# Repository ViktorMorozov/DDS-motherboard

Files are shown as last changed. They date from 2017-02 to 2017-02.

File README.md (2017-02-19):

# DDS-motherboard

A small motherboard to host a DDS AD9850, an Arduino Pro Clone and and an LCD. The project is composed of:
- Code to control the oscillation frequency through an AB encoder and display it in the LCD.
- KICad project with schematics and PCB design
- Milling file (G code) for CNC1610 and 0.1mm mill

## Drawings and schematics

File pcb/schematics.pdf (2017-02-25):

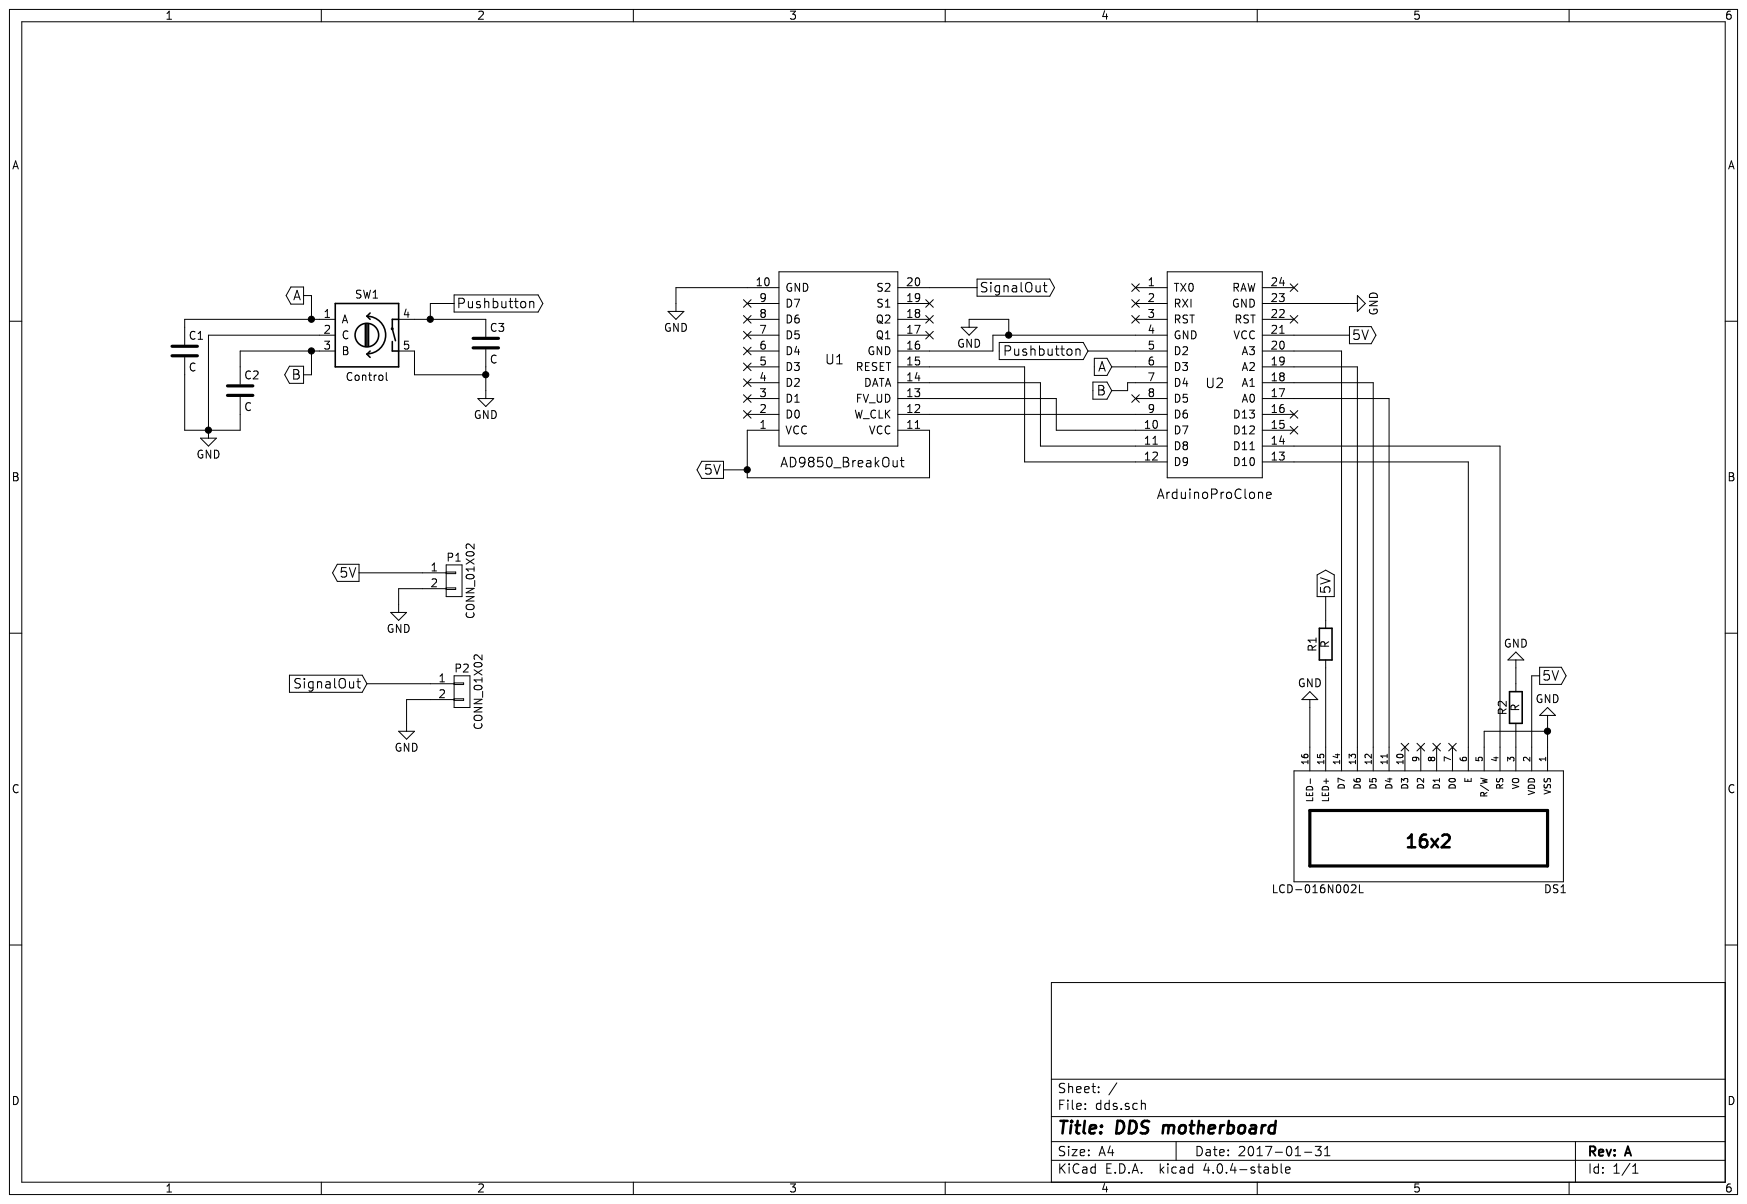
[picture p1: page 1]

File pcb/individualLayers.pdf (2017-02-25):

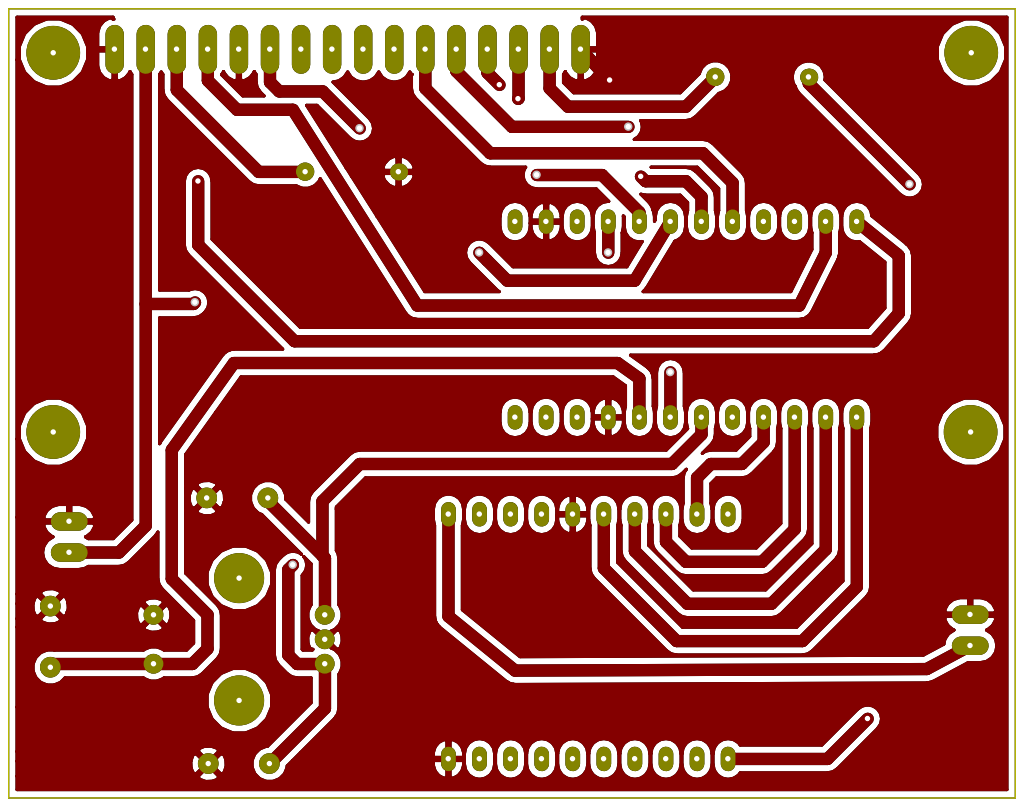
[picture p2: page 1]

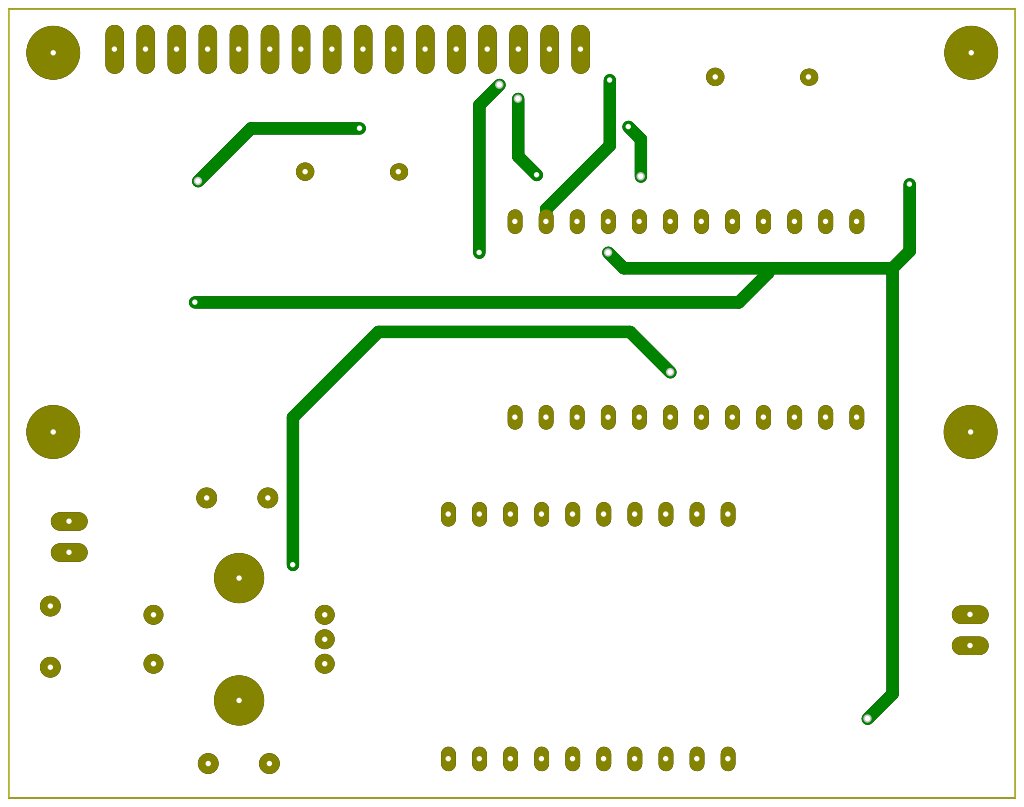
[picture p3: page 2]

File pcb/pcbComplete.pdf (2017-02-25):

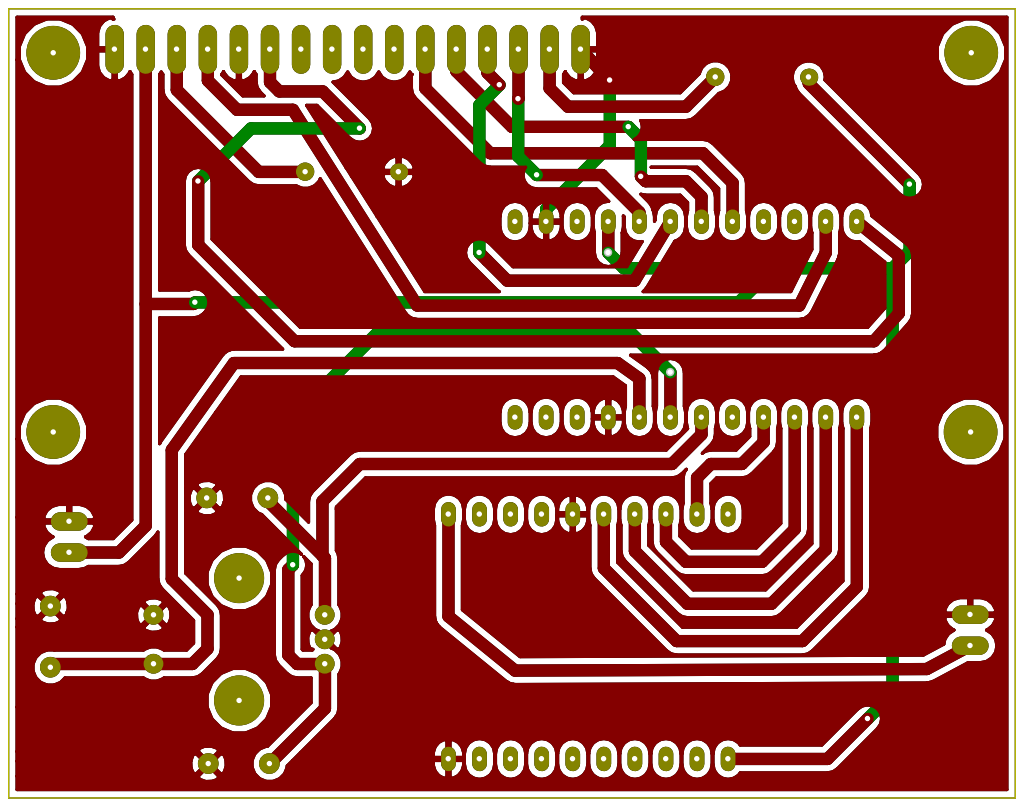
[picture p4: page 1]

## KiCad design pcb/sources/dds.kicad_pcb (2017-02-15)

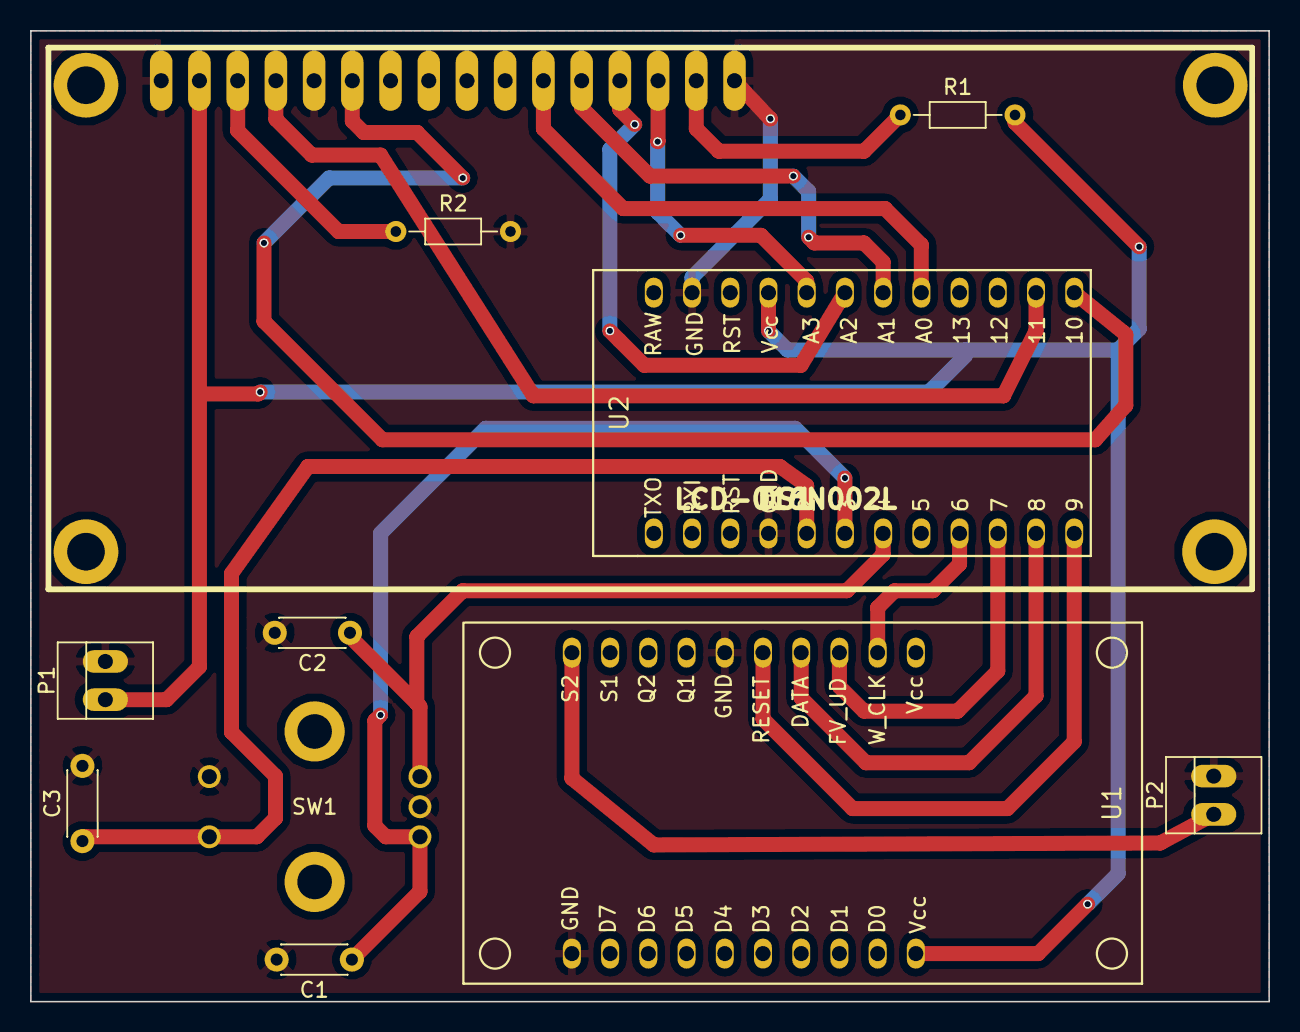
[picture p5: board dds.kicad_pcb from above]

Board: 2 copper layers, 82.3 x 64.5 mm, 11 parts (0 on the bottom side), 18 nets.

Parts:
C1, C2, C3: C; C_Disc_D4.3mm_W1.9mm_P5.00mm
DS1: LCD-016N002L; LCD-16x2
P1, P2: CONN_01X02; PINHEAD1-2
R1, R2: R; R_Axial_DIN0204_L3.6mm_D1.6mm_P7.62mm_Horizontal
SW1: Control; Encoder_PEC11-4215F-S00
U1: AD9850_BreakOut; AD9850_BreakoutBoard
U2: ArduinoProClone; ArduinoPro_Mini

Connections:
5V: DS1.2, P1.1, R1.2, U1.1, U1.11, U2.21
A: C1.1, SW1.1, U2.6
B: C2.1, SW1.3, U2.7
GND: C1.2, C2.2, C3.2, DS1.1, DS1.5, DS1.16, P1.2, P2.2, R2.2, SW1.2, SW1.5, U1.10, U1.16, U2.4, U2.23
unnamed: DS1.3, R2.1
unnamed: DS1.4, U2.14
unnamed: DS1.6, U2.13
unnamed: DS1.11, U2.17
unnamed: DS1.12, U2.18
unnamed: DS1.13, U2.19
unnamed: DS1.14, U2.20
unnamed: DS1.15, R1.1
unnamed: U1.12, U2.9
unnamed: U1.13, U2.10
unnamed: U1.14, U2.11
unnamed: U1.15, U2.12
Pushbutton: C3.1, SW1.4, U2.5
SignalOut: P2.1, U1.20

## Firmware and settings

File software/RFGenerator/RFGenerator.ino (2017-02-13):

#include <LiquidCrystal.h>
#include <AD9850.h>    //http://github.com/F4GOJ/AD9850

#define MHZ_10  10000000
#define MHZ     1000000
#define KHZ_100 100000
#define KHZ_10  10000
#define KHZ     1000
#define HZ_100  100
#define HZ_10   10

#define MAX_F     40000000
#define MIN_F     500000
#define INITIAL_F 7000000

#define IRQ_FILTER_MS 5
#define CW  1  // Clockwise rotation
#define CCW -1 // Counter Clockwise rotation

#define COMPENSATION 100

// Steps used in the 
double step[5] = {HZ_100,KHZ,KHZ_10,KHZ_100,MHZ};
int currentStep = 0; // Point to the current step
double freq = INITIAL_F; // Frequency in Hz

// Updated by the ISR (Interrupt Service Routine)
int updateScreenFlag = 1;

// Pin connections
const int PinA = 3;   // PinA and PinB for AB encoder
const int PinB = 4;
const int PinSW = 2;  // Push button

// Setup the LCD connections
LiquidCrystal lcd(11, 10, A0, A1, A2, A3);

void displayStep();
void displayFreq();
long getDigit(long mask, long freq);

void setup() {

  // Rotary pulses are INPUTs
  pinMode(PinA, INPUT);
  pinMode(PinB, INPUT);

  // Switch is floating so use the in-built PULLUP so we don't need a resistor
  pinMode(PinSW, INPUT_PULLUP);

  digitalWrite(PinA, HIGH);
  digitalWrite(PinB, HIGH); // Enable the internal pull ups in both input pins

  // Attach the routine to service the interrupts
  attachInterrupt(digitalPinToInterrupt(PinA), isrAB, LOW);
  
  lcd.begin(16, 2);
  DDS.begin(6, 7, 8, 9);
  DDS.calibrate(124999000);
  DDS.setfreq(freq, 0);
}

void loop() {
  
  // Is someone pressing the rotary switch?
  if ((!digitalRead(PinSW))) {
    //virtualPosition = 0;
    while (!digitalRead(PinSW))
      delay(10);
     currentStep = ((currentStep + 1) % 5);
    updateScreenFlag = 1;
  }
  
    DDS.setfreq(freq-COMPENSATION, 0);
    displayFreq();

    if (updateScreenFlag)
    {
      displayStep();
      updateScreenFlag = 0;
    }
}

void displayStep()
{
    lcd.clear();
    lcd.setCursor(0,1);
    lcd.print("Step:");
    lcd.setCursor(8,1);

    switch(currentStep) {
      case 0:
        lcd.print("100  Hz");
        break;
      case 1:
        lcd.print("  1 KHz");
        break;
      case 2:
        lcd.print(" 10 KHz");
        break;
      case 3:
        lcd.print("100 KHz");
        break;
      case 4:
        lcd.print("  1 MHz");
        break;
    }
}

void displayFreq()
{
    lcd.setCursor(0,0);
    lcd.print("Freq:");
    lcd.setCursor(6,0);
    lcd.setCursor(7,0);

    if ( freq >= MHZ_10) 
    {
      lcd.print((int) getDigit(MHZ_10,(long)freq));
    }
    else
    {
      lcd.print(" ");
    }
    
    lcd.setCursor(8,0);
    lcd.print((int)getDigit(MHZ,(long)freq % MHZ_10));
    lcd.setCursor(9,0);
    lcd.print(".");
    lcd.setCursor(10,0);
    lcd.print((int)getDigit(KHZ_100,(long)freq % MHZ));
    lcd.setCursor(11,0);
    lcd.print((int)getDigit(KHZ_10,(long)freq % KHZ_100));
    lcd.setCursor(12,0);
    lcd.print((int)getDigit(KHZ,(long)freq % KHZ_10));
    lcd.setCursor(13,0);
    lcd.print(",");
    lcd.setCursor(14,0);
    lcd.print((int)getDigit(HZ_100,(long)freq % KHZ));
    lcd.setCursor(15,0);
    lcd.print((int)getDigit(HZ_10,(long)freq % HZ_100));
}

long getDigit(long mask, long freq)
{
    return (freq/mask);
}


// https://github.com/futureshocked/arduino_sbs/blob/master/RotaryEncoder/rotaryEncoder/rotaryEncoder.ino
void isrAB ()  {
  
  static unsigned long lastInterruptTime = 0;
  unsigned long interruptTime = millis();
  char direction = 0;
  
  // If interrupts come faster than 5ms, assume it's a bounce and ignore
  if (interruptTime - lastInterruptTime > IRQ_FILTER_MS) {
    if (digitalRead(PinB) == LOW)
    {
      direction = CCW ;
    }
    else {
      direction = CW ;
    }

    if (freq >=MAX_F & direction == CW)
      freq = MAX_F;
    if (freq <= MIN_F & direction == CCW)
      freq = MIN_F;

    if ((freq >= MAX_F & direction == CCW) | 
      (freq <= MIN_F & direction == CW) |
      (freq > MIN_F & freq < MAX_F)
      )
      freq = freq + (direction * step[currentStep]);
      lastInterruptTime = interruptTime;
  }
}

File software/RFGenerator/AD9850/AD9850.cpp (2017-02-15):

/******************************************************************************************************************
 * Arduino library for AD9850
 * Created 23/08/2014
 * Christophe Caiveau f4goj@free.fr
 *
 * Use this library freely
 *
 * Hardware connections :
 * W_CLK   -> any pin
 * FQ_UD   -> any pin
 * DATA/D7 -> any pin
 * RESET   -> any pin
 *
 * Functions :
 * dds.begin(W_CLK pin, FQ_UD pin, DATA pin, RESET pin); Initialize the output pins and master reset the AD9850
 * dds.calibrate(frequency); Compensation of crystal oscillator frequency
 * dds.setfreq(frequency,phase); frequency in Hz, phase coded on 5 bits
 * dds.down(); power down mode reducing the dissipated power from 380mW to 30mW @5V
 * dds.up(); wake-up the AD9850
 *
 * AD9850 datasheet at http://www.analog.com/static/imported-files/data_sheets/AD9850.pdf
 *
 *****************************************************************************************************************/

#include "AD9850.h"

AD9850 DDS;

AD9850::AD9850() {

}

void AD9850::begin(int w_clk, int fq_ud, int data, int reset) {
	W_CLK = w_clk;
	FQ_UD = fq_ud;
	DATA = data;
	RESET = reset;
	deltaphase = 0;
	phase = 0;
	calibFreq = 125000000;
	begin_priv();
}

void AD9850::begin_priv() {
	pinMode(W_CLK, OUTPUT);
	pinMode(FQ_UD, OUTPUT);
	pinMode(DATA, OUTPUT);
	pinMode(RESET, OUTPUT);

	pulse(RESET);
	pulse(W_CLK);
	pulse(FQ_UD);
}

void AD9850::update() {

    for (int i=0; i<4; i++, deltaphase>>=8) {
     shiftOut(DATA, W_CLK, LSBFIRST, deltaphase & 0xFF);
    }
    shiftOut(DATA, W_CLK, LSBFIRST, phase & 0xFF);
    pulse(FQ_UD);
}


void AD9850::setfreq(double f, uint8_t p) {
	deltaphase = f * 4294967296.0 / calibFreq;
	phase = p << 3;
	update();
}


void AD9850::down() {
	pulse(FQ_UD);
	shiftOut(DATA, W_CLK, LSBFIRST, 0x04);
	pulse(FQ_UD);
}


void AD9850::up() {
	update();
}


void AD9850::calibrate(double TrimFreq)
{
	calibFreq = TrimFreq;
}


void AD9850::pulse(int pin) {
	digitalWrite(pin, HIGH);
	digitalWrite(pin, LOW);
}

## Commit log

2017-02-13 Added schematics and pcb design files
    [dds.kicad_pcb, dds.sch]
2017-02-13 Added initial version of the arduino firmware
2017-02-14 Gerber files for front layer and drill map.
    [dds-F.Cu.gbr, dds-drl_map.gbr, dds.drl]
2017-02-14 Gerber files moved and milling file created
    [dds-F.Cu.gbr, dds-drl_map.gbr, dds.drl]
2017-02-14 PDFs with schematics generated and files moved under sources folder
    [dds.kicad_pcb, dds.sch]
2017-02-14 Files moved to production and sources folder
    [dds.drl]
2017-02-15 Minor tracks re-route in front layer
    [dds.kicad_pcb]
2017-02-25 First milling attempt
    First milling attempt
2017-02-25 New production code with 0.1 mm cut depth
2017-02-25 Gerbers used to generate the G code
    [dds-F.Cu.gbr, dds-drl_map.gbr, dds.drl]
